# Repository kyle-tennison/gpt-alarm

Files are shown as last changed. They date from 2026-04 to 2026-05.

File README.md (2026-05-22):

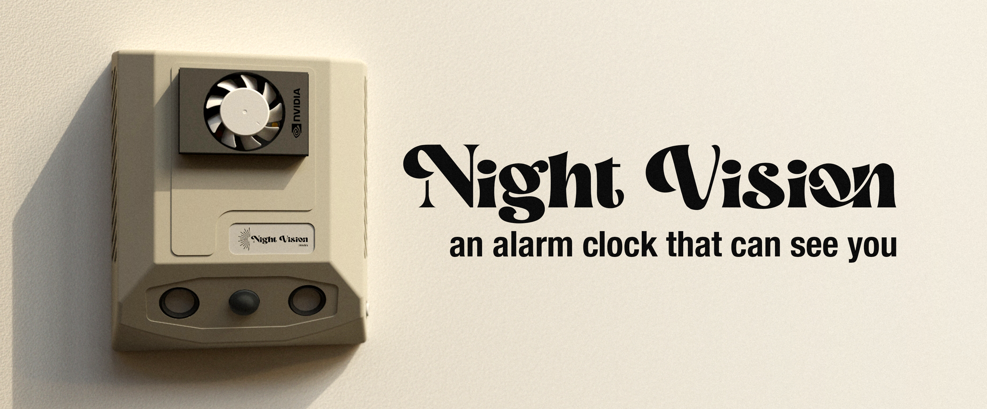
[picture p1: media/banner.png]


## Overview

Getting up in the morning sounds simple, but for many people, the hardest part is staying out of bed after the alarm goes off. Traditional alarms only solve half the problem: they can wake you up, but they can’t stop you from crawling back under the covers five minutes later.

Night Vision takes a different approach; it's an AI-powered alarm clock that uses an infrared camera and a fully local AI model to determine whether you’re still in bed. The alarm goes off at your set time, and only turns off when it sees you get out of bed. If the system detects that you’ve gone back to bed, the alarm starts again automatically. Once you’re actually up, it stays silent.

## Privacy

Having a camera pointed at your bed is unnerving to most people. However, it's really no different than having your phone camera near your bed. Nothing is being sent over the web: the photos are streamed directly to an on-prem vision-language model, and are never even written to disk. 

## Technical Overview

This project is implemented in Rust on a Jetson Orin Nano dev board. This is more of an embedded project than an AI project. Fast iteration is desired, so the following system was chosen in an attempt to maximize efficiency.

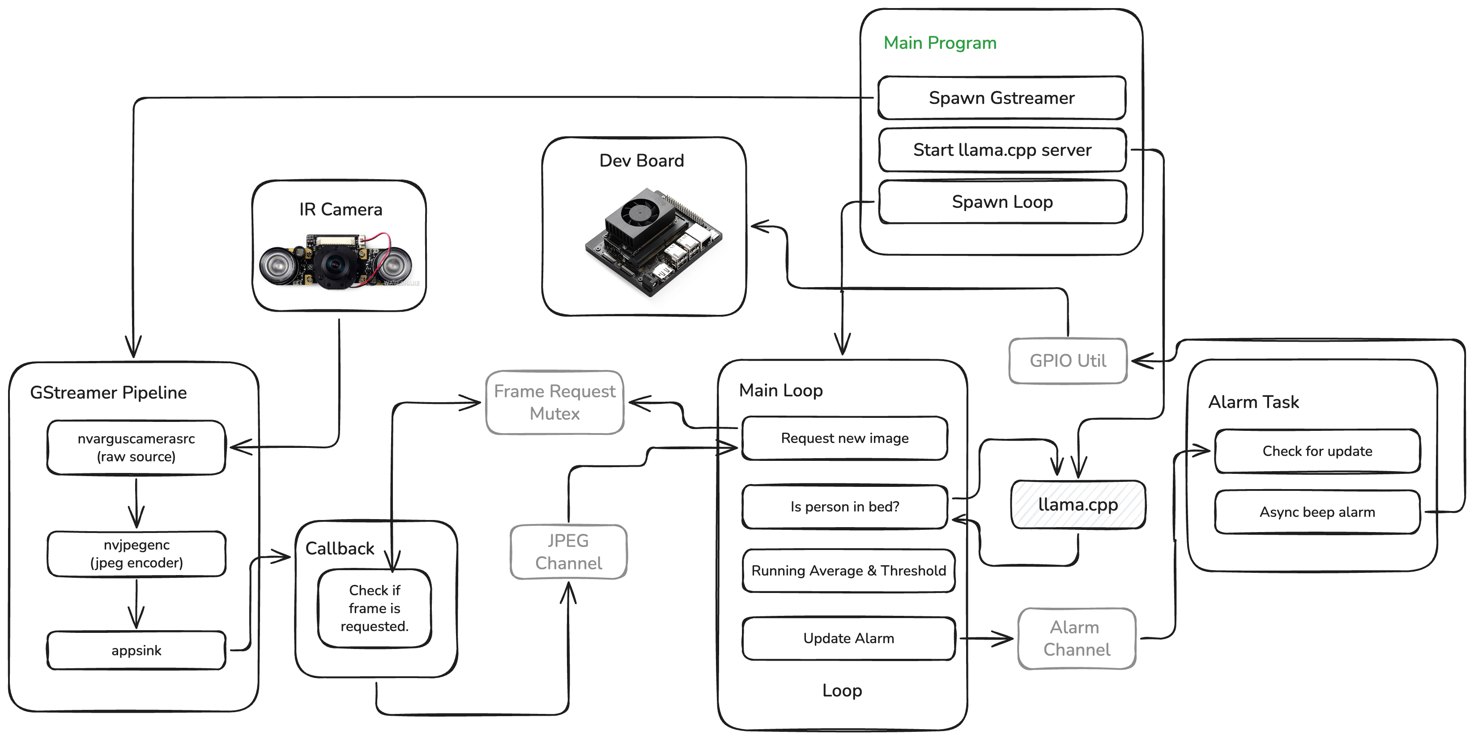
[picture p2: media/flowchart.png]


### GStreamer

The [`gstreamer-rs`](https://crates.io/crates/gstreamer) crate was used to implement GStreamer directly in Rust. This allows frames to be read directly from a callback function. This bypasses any network or file I/O, and doesn't need to make any kernel calls whatsoever because everything happens in shared memory[^1]. 

There is a bit of time lost between requesting a frame in the "Frame Request Mutex" and the time the callback is triggered. However, the current implementation prefers a more recent frame over the fastest frame. There is no point in running the loop on an old frame.

### Vision Language Model

[`llama.cpp`](https://github.com/ggml-org/llama.cpp) is used for all AI-related processing. It was recompiled to take full advantage of the NVIDIA hardware. The model of choice is a tiny 450M vision-language model from LiquidAI: [`LiquidAI/LFM2.5-VL-450M-GGUF`](https://huggingface.co/LiquidAI/LFM2.5-VL-450M-GGUF). With the NVIDIA chip, the entire loop, from image to prediction, takes 0.3s. 

### CAD Model

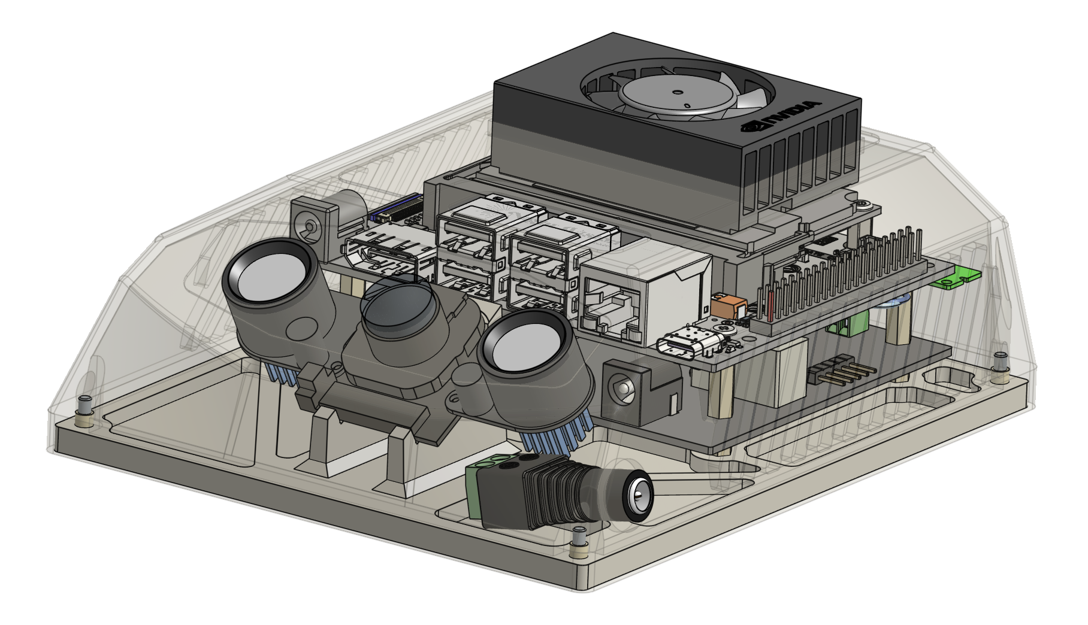
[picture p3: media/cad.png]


A public Onshape CAD model is provided [here](https://cad.onshape.com/documents/bcaebb5bd275e77d30be5dbb/w/f60a4044710e4fea0219c5aa/e/11bcaacbcd1531fb40906f8f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). I was going for an 80s beige vibe, which a lot of people hate, but I personally love.

### PCB

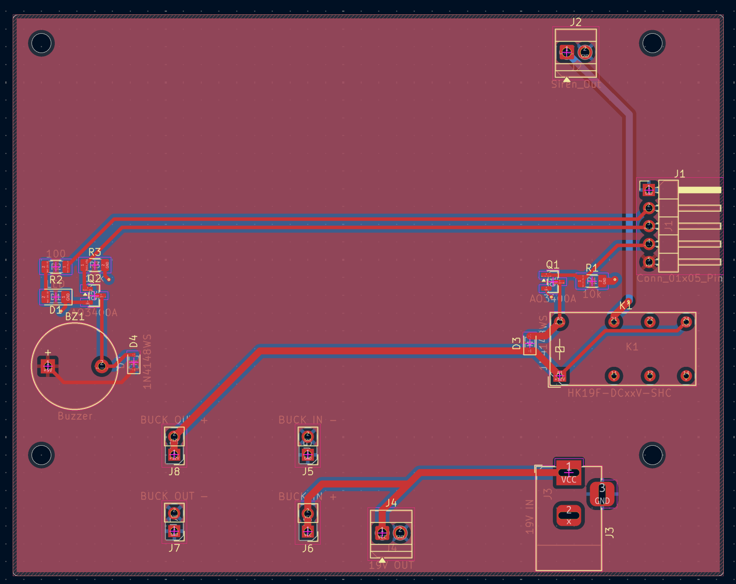
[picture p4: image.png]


A very simple PCB sits under the Jetson Orin Nano dev board. KiCad files for this are in `board/`. There is a spot for a relay here that is unused, but might be useful in a future version. The main purpose of this board is to operate the buzzer and an indicator LED.

## Unrelated

### 15-year-old Attempt

For a very long time, I've wanted an alarm clock that could detect when I was in bed. When I was 15, I tried a very similar approach using a *very* sketchy force transducer made from my parents' bathroom scale. This is what it looked like:



This worked for a couple of days, but I had to plug my laptop into it every night, so it didn't last long. I remember at the time contemplating running a CNN on a Raspberry Pi that could monitor a video feed of my bed. I actually found the blog post where I was thinking about this:

> "I also considered the option of training an AI to use a picture to determine if I was in bed or not. I also ended up deciding against this because of the sheer complexity."

From a [blog post](https://rannsyt.blogspot.com/2020/10/i-built-smart-bed-blog.html) in 2020.

And it's good that I dropped that idea, because a conventional CNN would be extremely sensitive to any change in the environment. That is if I could even get it trained in the first place. It would require a lot of training data, and the moment my room changed (new picture, different bedding, etc.), the model could easily start spitting out garbage.

[^1]: Don't quote me on the kernel part—I might be mistaken.

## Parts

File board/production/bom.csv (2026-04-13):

Designator | Footprint | Quantity | Value | LCSC Part #
BZ1 | MagneticBuzzer_StarMicronics_TMB | 1 | Buzzer
D1 | 1206 | 1 | LED
D3, D4 | D_SOD-323 | 2 | 1N4148WS
J1 | PinHeader_1x05_P2.54mm_Horizontal | 1 | Conn_01x05_Pin
J2 | TerminalBlock_Xinya_XY308-2.54-2P_1x02_P2.54mm_Horizontal | 1 | Siren_Out
J3 | BarrelJack_Horizontal | 1 | 19V IN
J4 | TerminalBlock_Xinya_XY308-2.54-2P_1x02_P2.54mm_Horizontal | 1 | 19V OUT
J5 | PinHeader_1x02_P2.54mm_Vertical | 1 | BUCK IN -
J6 | PinHeader_1x02_P2.54mm_Vertical | 1 | BUCK IN +
J7 | PinHeader_1x02_P2.54mm_Vertical | 1 | BUCK OUT -
J8 | PinHeader_1x02_P2.54mm_Vertical | 1 | BUCK OUT +
K1 | Relay_DPDT_Finder_30.22 | 1 | HK19F-DCxxV-SHC
Q1, Q2 | SOT-23 | 2 | AO3400A
R1, R3 | 1206 | 2 | 10k
R2 | 1206 | 1 | 100

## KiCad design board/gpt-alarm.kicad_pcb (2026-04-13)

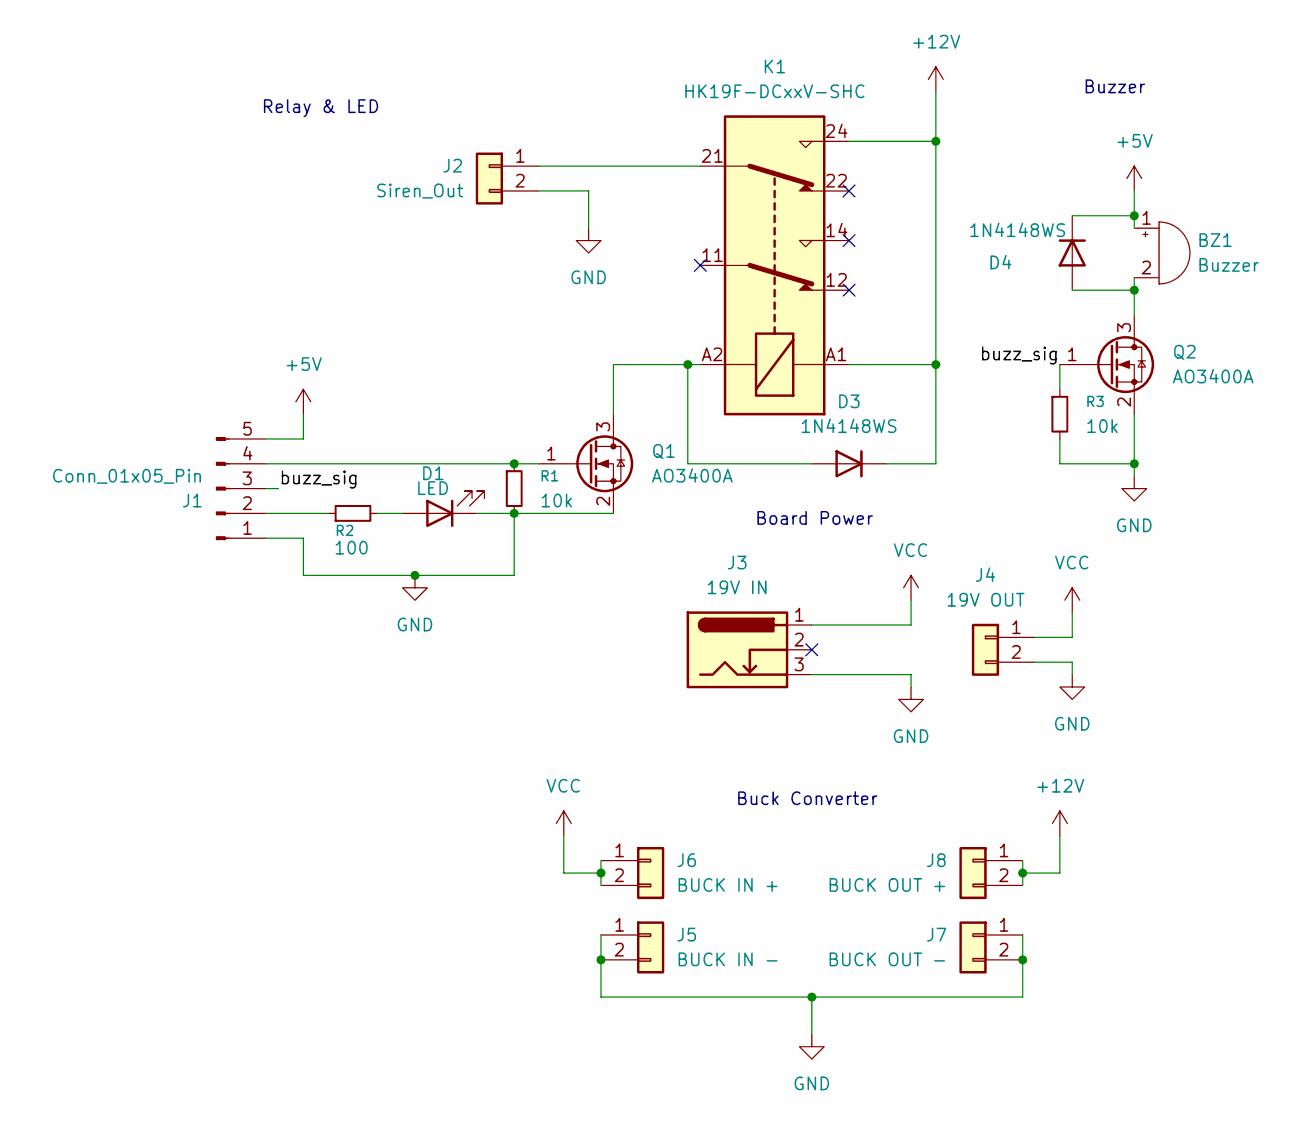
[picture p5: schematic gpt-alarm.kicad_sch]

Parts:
BZ1: Buzzer; MagneticBuzzer_StarMicronics_TMB
D1: LED; D_1206_3216Metric
D3, D4: 1N4148WS; D_SOD-323
J1: Conn_01x05_Pin; PinHeader_1x05_P2.54mm_Horizontal
J2: Siren_Out; TerminalBlock_Xinya_XY308-2.54-2P_1x02_P2.54mm_Horizontal
J3: 19V IN; BarrelJack_Horizontal
J4: 19V OUT; TerminalBlock_Xinya_XY308-2.54-2P_1x02_P2.54mm_Horizontal
J5: BUCK IN -; PinHeader_1x02_P2.54mm_Vertical
J6: BUCK IN +; PinHeader_1x02_P2.54mm_Vertical
J7: BUCK OUT -; PinHeader_1x02_P2.54mm_Vertical
J8: BUCK OUT +; PinHeader_1x02_P2.54mm_Vertical
K1: HK19F-DCxxV-SHC; Relay_DPDT_Finder_30.22
Q1, Q2: AO3400A; SOT-23
R1, R3: 10k; R_1206_3216Metric
R2: 100; R_1206_3216Metric

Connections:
+5V: BZ1.1 (+), D4.1 (K), J1.5
+12V: D3.1 (K), J8.1, J8.2, K1.24, K1.A1
/buzz_sig: J1.3, Q2.1 (G), R3.1
GND: D1.1 (K), J1.1, J2.2, J3.3, J4.2, J5.1, J5.2, J7.1, J7.2, Q1.2 (S), Q2.2 (S), R1.2, R3.2
unnamed: BZ1.2 (-), D4.2 (A), Q2.3 (D)
unnamed: D1.2 (A), R2.2
unnamed: D3.2 (A), K1.A2, Q1.3 (D)
unnamed: J1.2, R2.1
unnamed: J1.4, Q1.1 (G), R1.1
unnamed: J2.1, K1.21
VCC: J3.1, J4.1, J6.1, J6.2

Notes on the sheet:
Relay & LED
Buck Converter
Board Power
Buzzer

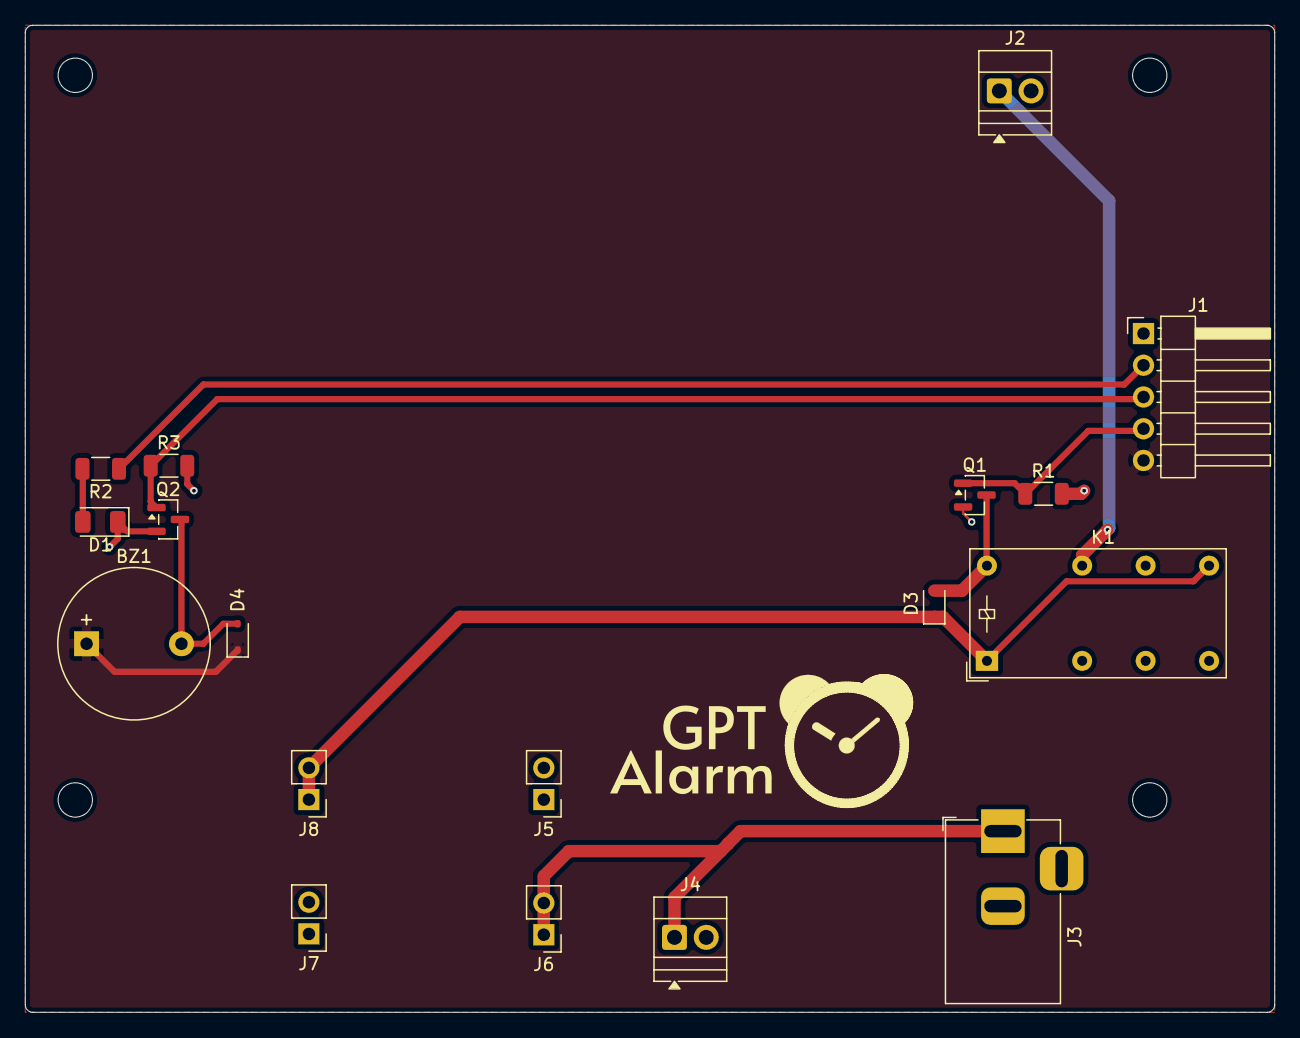
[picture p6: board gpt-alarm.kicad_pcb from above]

Board: 2 copper layers, 100.0 x 79.0 mm, 18 parts (0 on the bottom side), 11 nets.

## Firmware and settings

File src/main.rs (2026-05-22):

use std::{cell::RefCell, rc::Rc, thread};

use tokio::runtime::Runtime;

use crate::{
    camera::{CamService, FrameFetcher},
    dispatcher::Dispatcher,
};

mod camera;
mod dispatcher;
mod gpio;
mod led;
mod llama;
mod sound;

// main thread (mt)
fn main() {
    // force root
    let is_root = unsafe { libc::getuid() } == 0;
    assert!(is_root, "must be sudo for GPIO");

    // camera servie needs to run on the main thread
    let mut cam_service = CamService::start();
    let frame_fetcher = cam_service.get_fetcher().unwrap();

    // main program runs here
    let at = thread::Builder::new()
        .name("auxillary-thread".to_string())
        .spawn(move || {
            let rt = Runtime::new().expect("failed to create tokio runtime");
            rt.block_on(async {
                at_prog(frame_fetcher).await;
            });
        })
        .unwrap();

    // need to do some bs to get this
    let at = Rc::new(RefCell::new(Some(at)));
    let at_closure = at.clone();

    let poll_alive = move || {
        let is_alive = at_closure
            .borrow()
            .as_ref()
            .is_some_and(|f| !f.is_finished());
        println!("info: pulling aux thread for life: {is_alive}");
        is_alive
    };

    cam_service.run_forever(poll_alive);
    eprintln!("error: camera loop exited");

    at.borrow_mut().take().unwrap().join().unwrap()
}

// auxillary thread program. everything besides camera IO runs here
async fn at_prog(frame_fetcher: FrameFetcher) {
    println!("info: start at_prog");
    let dispatcher = Dispatcher::startup(frame_fetcher).await;
    println!("debug: constructed");
    dispatcher.run().await;
}

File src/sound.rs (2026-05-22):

use std::sync::mpsc::{self, TryRecvError};
use std::{sync::Arc, time::Duration};

use crate::gpio::GPIOUtil;

#[allow(dead_code)]
#[derive(PartialEq, Debug)]
pub enum AlarmState {
    Active,
    Count(u8),
    Error,
    Disarmed,
}

pub struct SoundUtil {
    tx: mpsc::Sender<AlarmState>,
    gpio_util: Arc<GPIOUtil>,
}

impl SoundUtil {
    pub fn new(gpio_util: Arc<GPIOUtil>) -> Self {
        let (tx, rx) = mpsc::channel::<AlarmState>();

        let gpio_ref = gpio_util.clone();

        tokio::spawn(async {
            Self::async_worker(rx, gpio_ref).await;
        });

        SoundUtil {
            tx,
            gpio_util: gpio_util,
        }
    }

    async fn async_worker(rx: mpsc::Receiver<AlarmState>, gpio_util: Arc<GPIOUtil>) {
        println!("info: sound task started");
        let mut alarm_state = AlarmState::Disarmed;

        loop {
            match rx.try_recv() {
                Ok(update) => {
                    if update != alarm_state {
                        alarm_state = update;
                        println!("debug: updated alarm state to {:?}", alarm_state);
                    }
                    continue; // loop until empty
                }
                Err(TryRecvError::Empty) => (),
                Err(TryRecvError::Disconnected) => break,
            };

            match alarm_state {
                AlarmState::Active => {
                    gpio_util.set_buzzer(true);
                    tokio::time::sleep(Duration::from_millis(125)).await;
                    gpio_util.set_buzzer(false);
                    tokio::time::sleep(Duration::from_millis(125)).await;

                    gpio_util.set_buzzer(true);
                    tokio::time::sleep(Duration::from_millis(125)).await;
                    gpio_util.set_buzzer(false);

                    tokio::time::sleep(Duration::from_millis(750)).await;
                }
                AlarmState::Count(n) => {
                    for _ in 0..n {
                        gpio_util.set_buzzer(true);
                        tokio::time::sleep(Duration::from_millis(125)).await;
                        gpio_util.set_buzzer(false);
                        tokio::time::sleep(Duration::from_millis(125)).await;
                    }
                    alarm_state = AlarmState::Disarmed;
                }
                AlarmState::Error => {
                    gpio_util.set_buzzer(true);
                    tokio::time::sleep(Duration::from_millis(500)).await;
                    gpio_util.set_buzzer(false);
                    break;
                }
                AlarmState::Disarmed => tokio::time::sleep(Duration::from_millis(500)).await,
            };
        }
        println!("warn: sound async worker exiting")
    }

    pub fn set_state(&self, state: AlarmState) {
        println!("debug: requesting sound state {state:?}");
        self.tx
            .send(state)
            .expect("unable to update SoundUtil state");
    }

    pub async fn testsound(&self) {
        println!("debug: playing testsound");
        self.set_state(AlarmState::Count(2));
        tokio::time::sleep(Duration::from_millis(1300)).await;
        println!("debug: playing complete");
    }

    pub fn signal_start(&self) {
        self.set_state(AlarmState::Count(2));
    }
}

impl Drop for SoundUtil {
    fn drop(&mut self) {
        self.gpio_util.set_buzzer(true);
        std::thread::sleep(Duration::from_millis(750));
        self.gpio_util.set_buzzer(false);
    }
}

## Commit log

2026-04-12 perf: threaded camera
2026-04-12 perf: resize camera at startup
2026-04-12 feat: carrier schematic
    [gpt-alarm.kicad_pcb, gpt-alarm.kicad_sch]
2026-04-13 feat: pcb layout
    [bom.csv, designators.csv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]
2026-05-20 feat/nv rewrite (#1)
    * feat: gst camera
    * feat: buzzer impl
    * feat: startup tests
    * feat: integrate pipeline
    * lint
    * fix: use appsink for image pipeline
    * wip: led service
    * fix: memory runaway
    [gpio.rs, led.rs, main.rs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]
2026-05-22 fix: loop when update
    [led.rs, sound.rs]
